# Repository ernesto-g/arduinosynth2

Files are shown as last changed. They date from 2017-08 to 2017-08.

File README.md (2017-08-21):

# Arduino digital polyphonic synth with analog filter

Six voices synth with MIDI input controlled by an arduino microcontroller. 

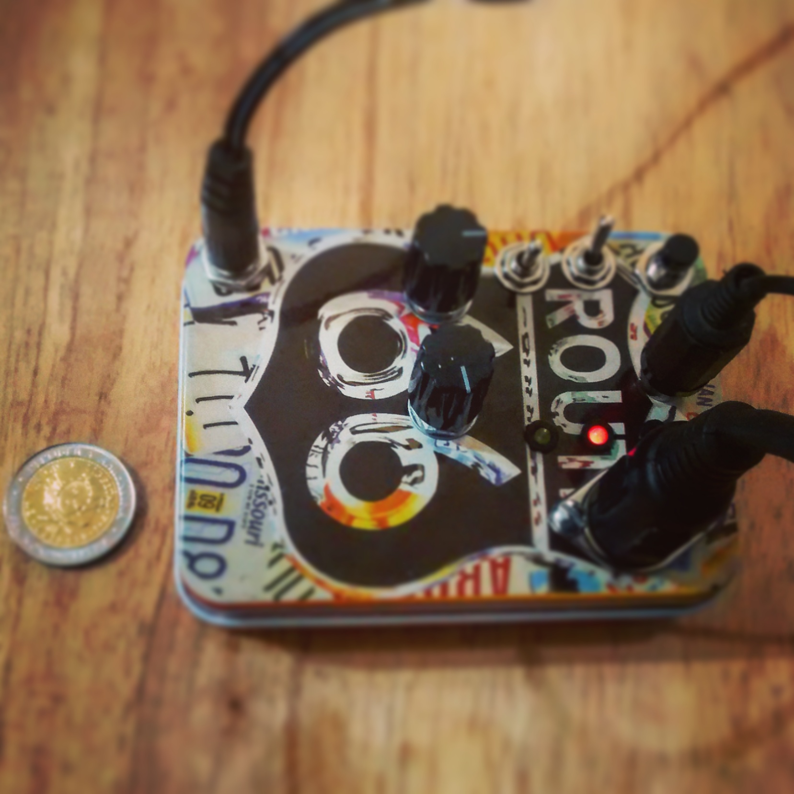
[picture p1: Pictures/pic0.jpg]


Synth features:
  - MIDI input
  - 76 key support (21 to 96)
  - Six digital voices:
    - square waveform 50%
    - square waveform 25%  
  - Two envolope generators (EG) with attack, and release controls
  - One digital 8 bit LFO with:
    - 0.5Hz to 30Hz tune control.
    - Sine and exponential waveforms
  - One analog filter with:
	- Cutoff freq and resonance controls.
	- Modulated by LFO and EG2
  - One digital VCA modulated by EG1 and LFO
  - Digital features:
      - Arpeggiator: Repeat until 10 keys pressed at the same time with speed control.
      - Two modes: 
        - MODE 0:EG with attack and release parameters.
        - MODE 1:EG with attack, sustain and release parameters.

  - MIDI controls info:
      - MIDI channel : 1  
      - EG1 Attack   : control number 74
      - EG1 Release  : control number 71
      - EG2 Attack   : control number 73
      - EG2 Release  : control number 72
      - LFO Speed    : control number 75
      - VCA modulation (EG1 or LFO balance) : control number 77
      - VCF modulation (EG2 or LFO balance) : control number 76
      - Arpeggiator speed : control number 78

This project contains:
  - Arduino nano Firmware
  - Schematics and PCB

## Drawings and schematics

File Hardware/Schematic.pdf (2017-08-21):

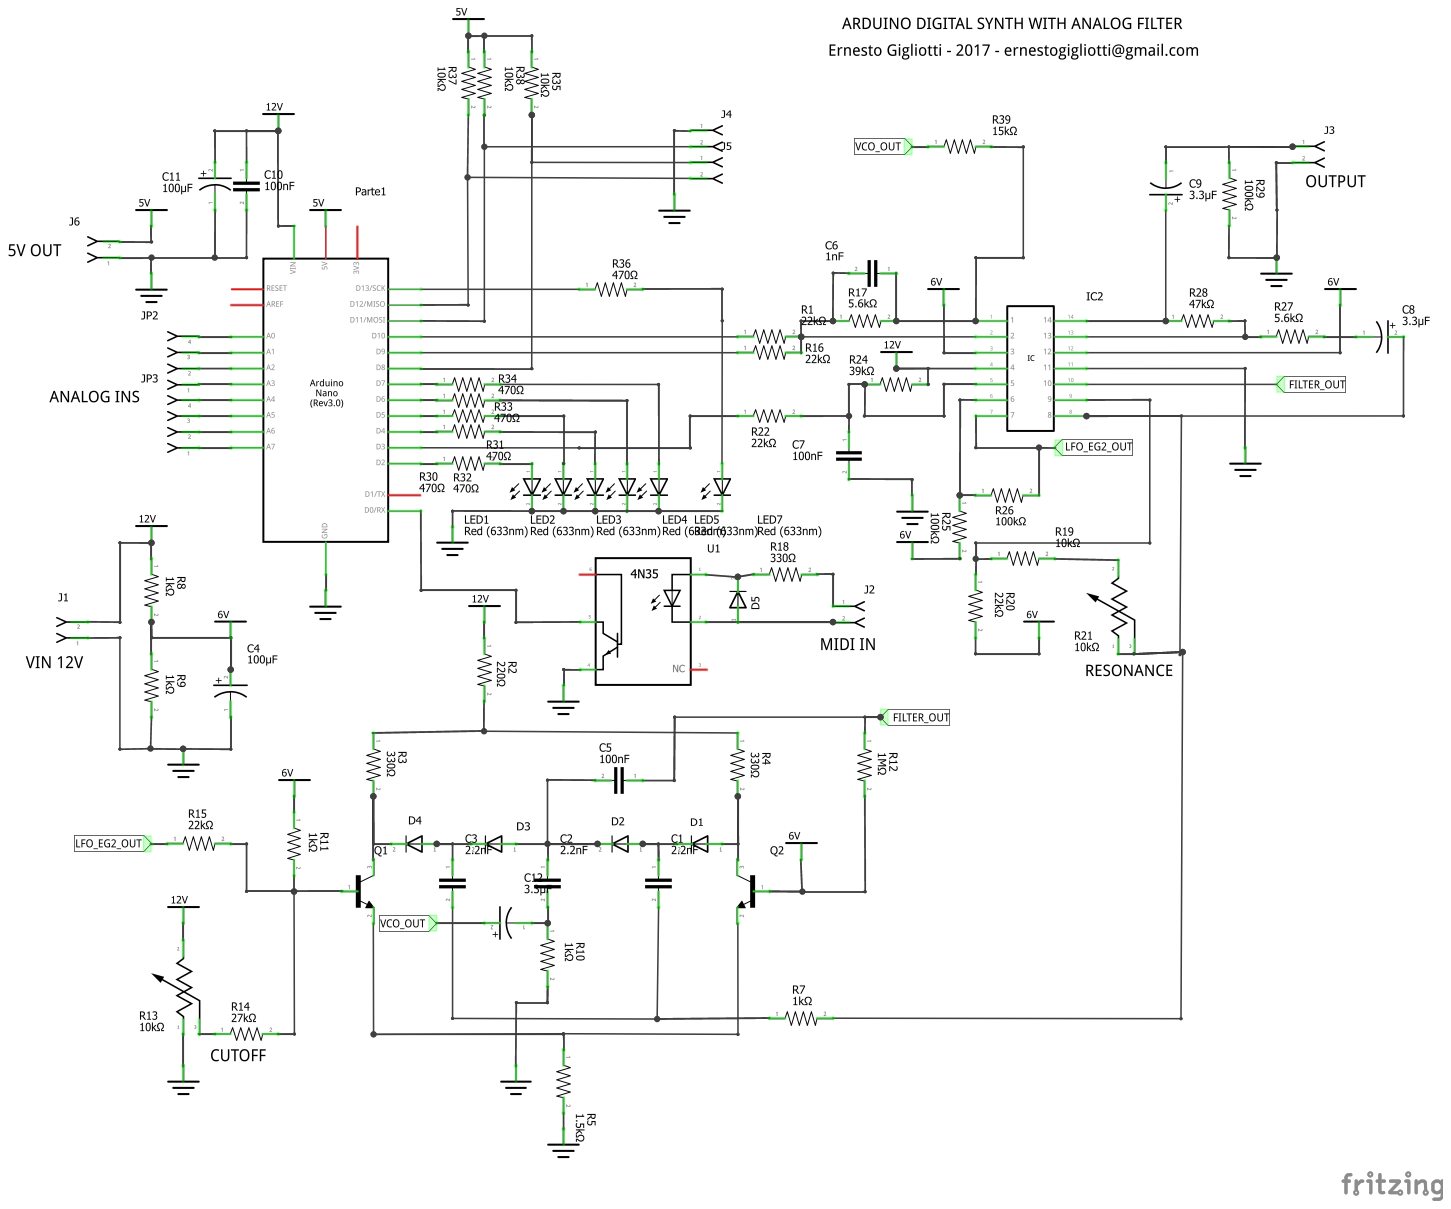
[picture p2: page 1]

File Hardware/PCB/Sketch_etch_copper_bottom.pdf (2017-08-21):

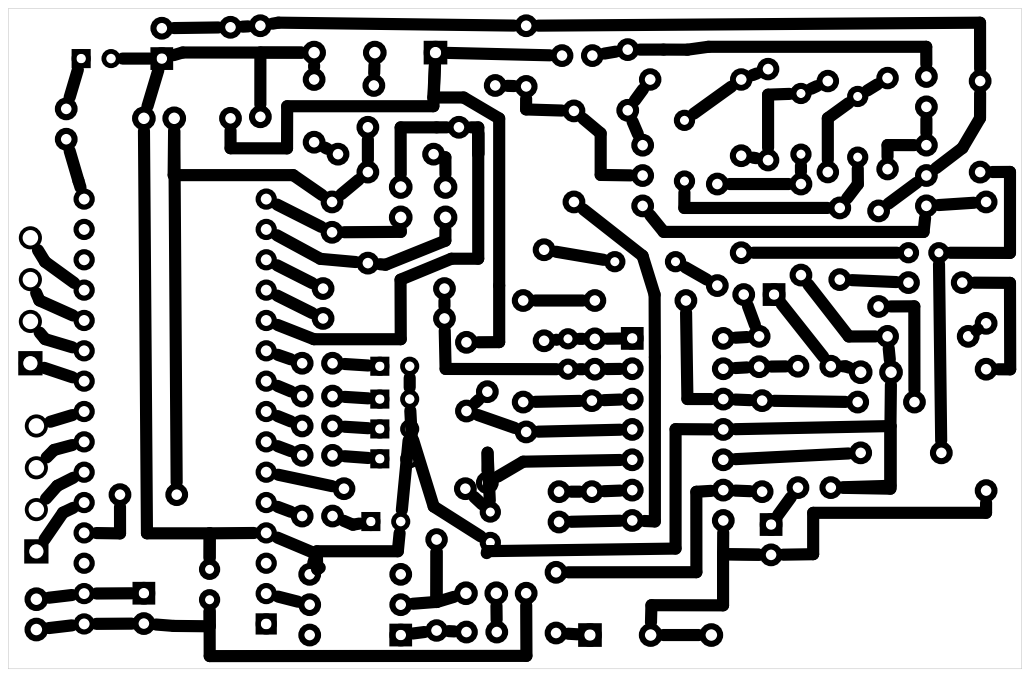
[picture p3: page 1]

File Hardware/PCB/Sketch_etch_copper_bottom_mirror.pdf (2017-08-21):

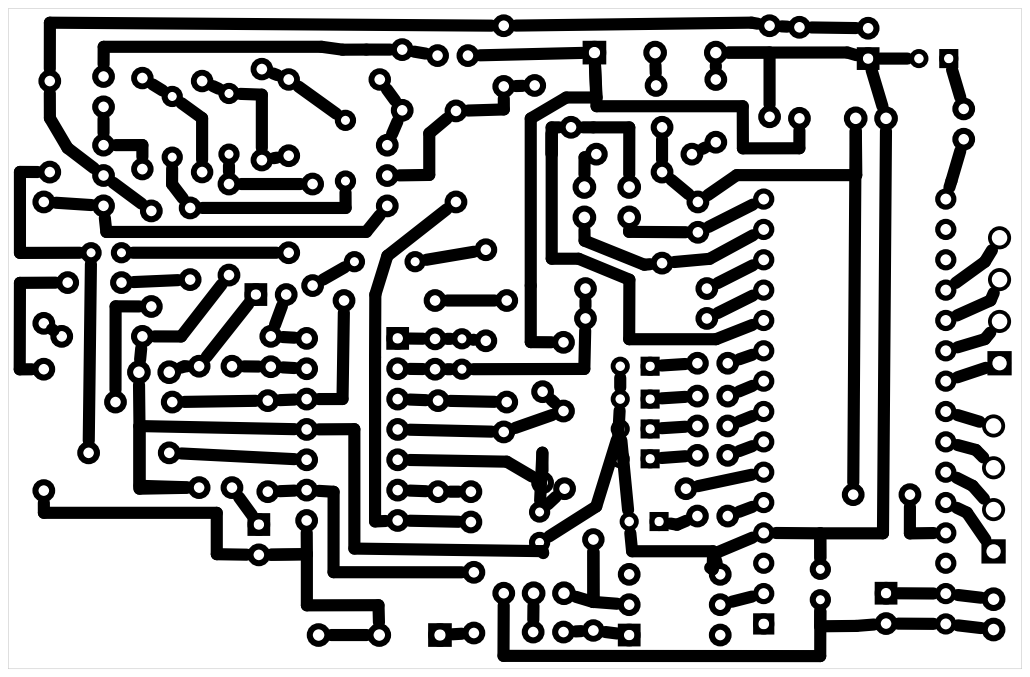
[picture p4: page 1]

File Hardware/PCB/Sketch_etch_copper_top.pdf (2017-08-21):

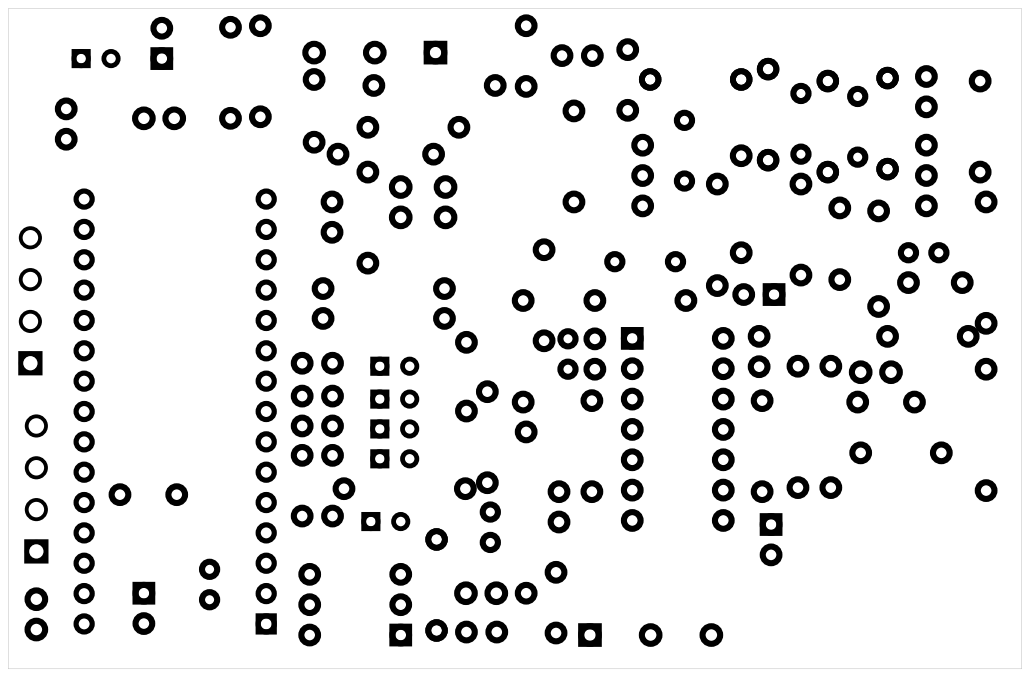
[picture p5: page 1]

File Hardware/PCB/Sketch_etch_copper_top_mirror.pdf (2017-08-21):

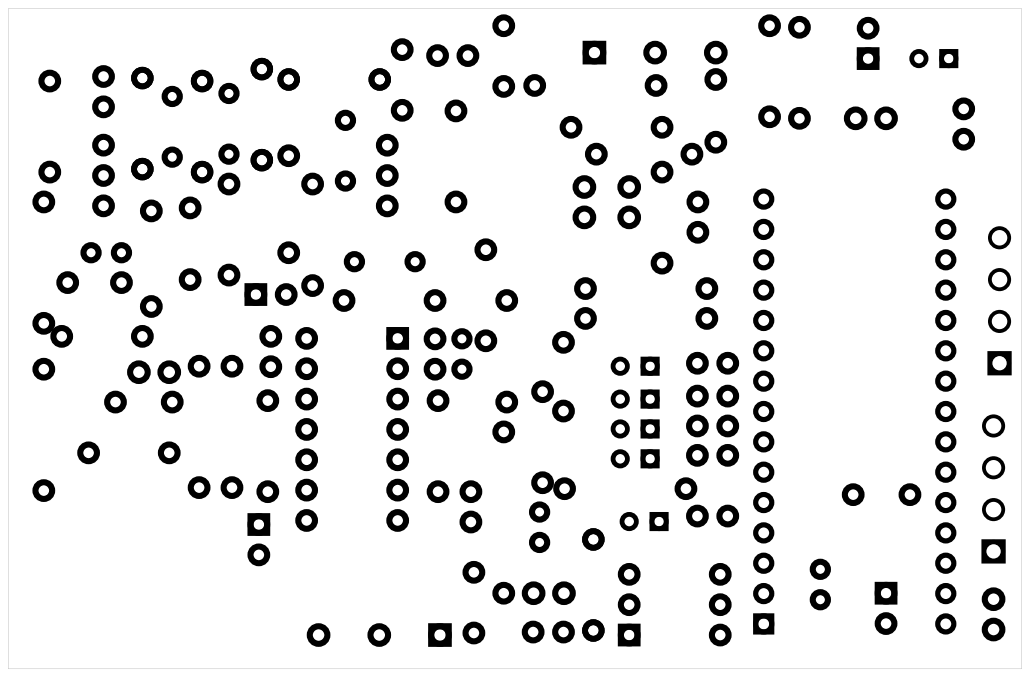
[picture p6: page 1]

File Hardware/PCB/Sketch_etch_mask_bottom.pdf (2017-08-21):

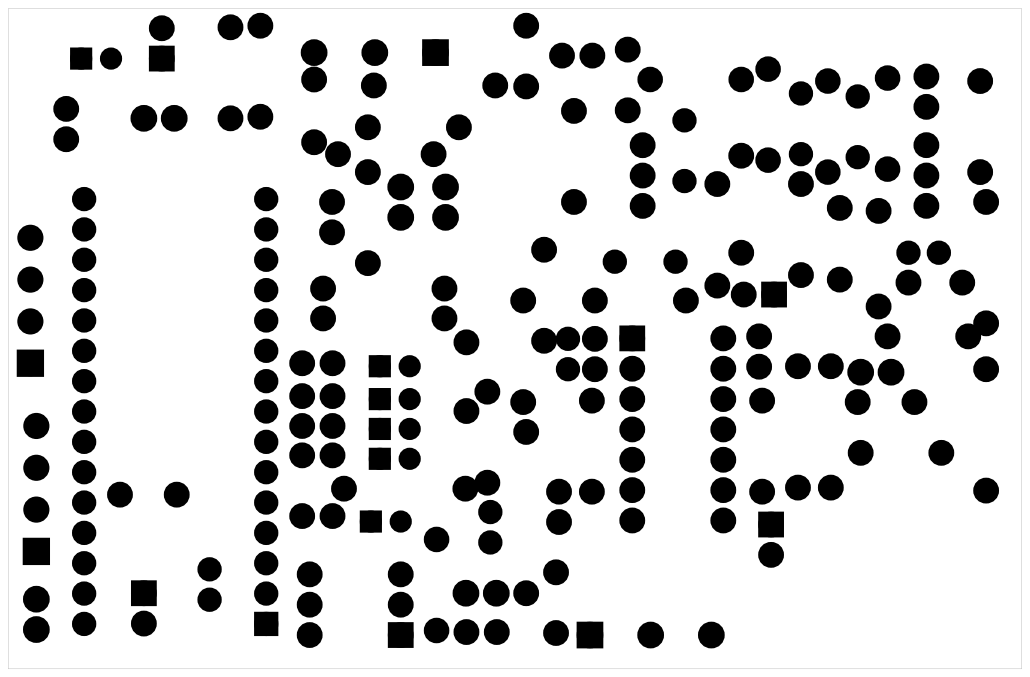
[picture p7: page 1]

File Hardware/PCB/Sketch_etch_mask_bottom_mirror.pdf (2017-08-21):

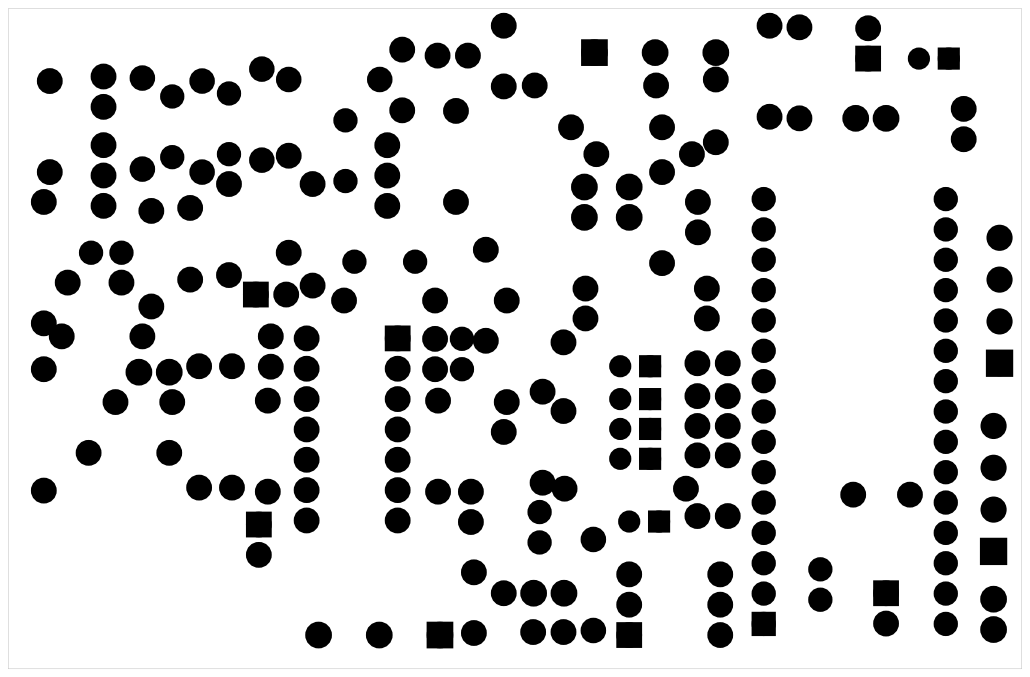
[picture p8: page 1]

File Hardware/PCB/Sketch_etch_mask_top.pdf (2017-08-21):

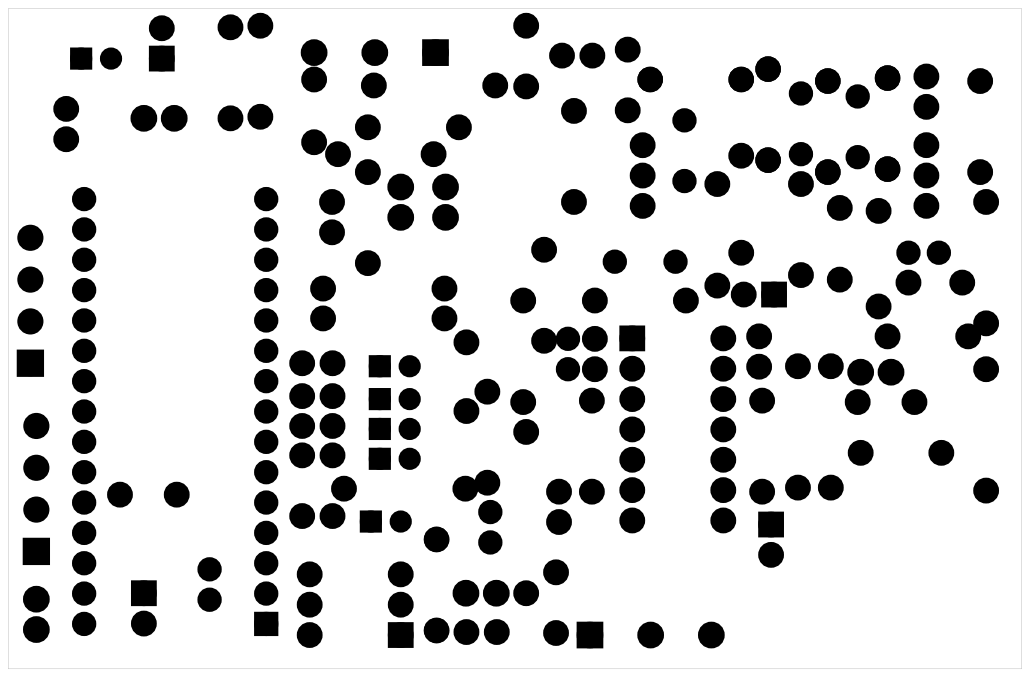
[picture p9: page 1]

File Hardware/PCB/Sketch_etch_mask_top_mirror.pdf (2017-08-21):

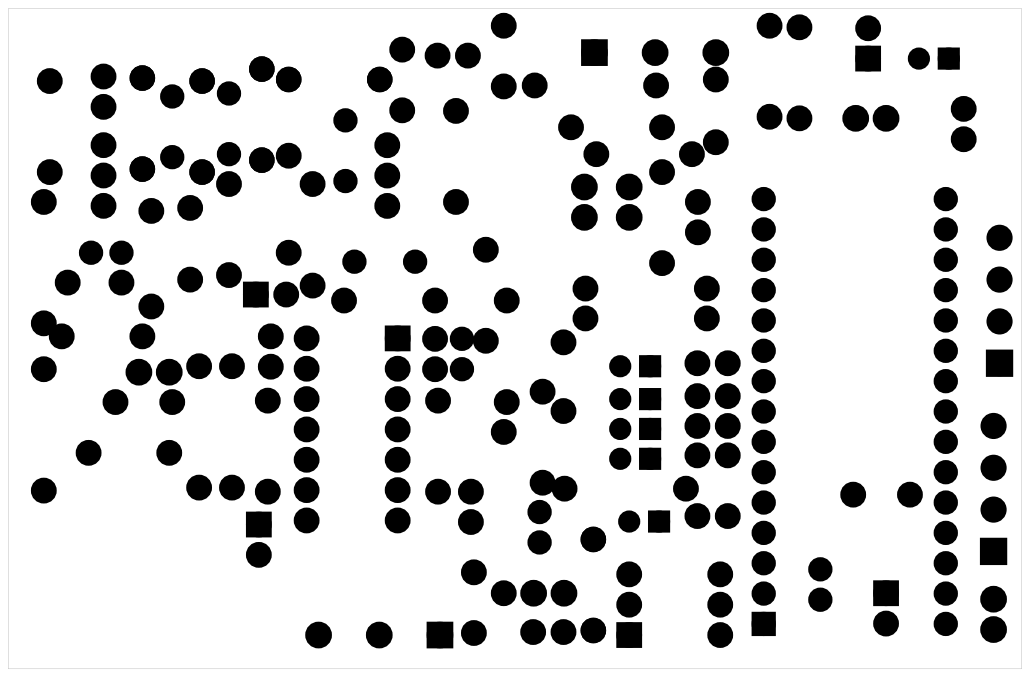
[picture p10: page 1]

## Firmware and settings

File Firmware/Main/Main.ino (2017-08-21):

/**
 *  Arduino Digital Synth with analog filter
    Copyright (C) <2017>  Ernesto Gigliotti <ernestogigliotti@gmail.com>

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
    You should have received a copy of the GNU General Public License
    along with this program.  If not, see <http://www.gnu.org/licenses/>.
 */
#include "Config.h"
#include "MidiManager.h"
#include "Lfo.h"
#include "AnalogIns.h"
#include "FrontPanel.h"
#include "SequencerManager.h"
#include "VCOs.h"

volatile unsigned char bufferRx[5][3];
volatile unsigned char bufferRxIndex[5]={0,0,0,0,0};
volatile unsigned char bufferRxNewPacket[5]={0,0,0,0,0};
volatile unsigned char currentBufferIndex=0;

ISR(USART_RX_vect)
{
    if(bufferRxNewPacket[currentBufferIndex]==0)
    {
      bufferRx[currentBufferIndex][bufferRxIndex[currentBufferIndex]] = UDR0;
      bufferRxIndex[currentBufferIndex]++;
      if(bufferRxIndex[currentBufferIndex]>=3)
      {
        bufferRxNewPacket[currentBufferIndex] = 1;
        currentBufferIndex++;
        if(currentBufferIndex>=5)
          currentBufferIndex=0;
      }
    }
    else
    {
      uint8_t r = UDR0;
      r = r; // silence compiler warnings  
    }
}

void setup() {
  config_init();    
  vcos_init();
  lfo_init();
  ain_init();
  frontp_init();
  seq_init();
  midi_init();
}



void loop() {

  while(1)
  {
    // MIDI Reception
    unsigned char index;
    for(index=0; index<5; index++)
    {
      if(bufferRxNewPacket[index])
      {       
          midi_stateMachine(bufferRx[index][0]);
          midi_stateMachine(bufferRx[index][1]);
          midi_stateMachine(bufferRx[index][2]);      
          bufferRxIndex[index]=0;
          bufferRxNewPacket[index]=0;
      }
    }
    //_______________    

    lfo_cooperativeTimer0Interrupt();


    vcos_egStateMachine();

    midi_repeatManager();

    frontp_state_machine();

    /* //NOT USED
    ain_state_machine();

    seq_stateMachine();
    */
    
  }

}

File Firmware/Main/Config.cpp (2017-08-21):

/**
 *  Arduino Digital Synth with analog filter
    Copyright (C) <2017>  Ernesto Gigliotti <ernestogigliotti@gmail.com>

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
    You should have received a copy of the GNU General Public License
    along with this program.  If not, see <http://www.gnu.org/licenses/>.
 */
//#include <HardwareSerial.h>
#include <Arduino.h>
#include "Config.h"

#define USART_BAUDRATE 31250
#define BAUD_PRESCALE (((F_CPU / (USART_BAUDRATE * 16UL))) - 1)
 
void config_init(void)
{
  
  // Configure serial port for MIDI input
  //Serial.begin(31250); 
    UBRR0L = (uint8_t)(BAUD_PRESCALE & 0xff);
    UBRR0H = (uint8_t)(BAUD_PRESCALE >> 8);
    UCSR0B =
        /* interrupt on receive */
        (1 << RXCIE0) | (1 << TXEN0) |
        (1 << RXEN0);
    UCSR0C =
        /* no parity bit */
        (0 << UPM01) |
        (0 << UPM00) |
        /* asyncrounous USART */
        (0 << UMSEL01) |
        (0 << UMSEL00) |
        /* one stop bit */
        (0 << USBS0) |
        /* 8-bits of data */
        (1 << UCSZ01) |
        (1 << UCSZ00);

    DDRD = 0x00;
    DDRB = 0x20;  
  //_____________________________________


  // Configure TIMER1 for PWM (VCO1 and VCO2 Control Voltage)
  DDRB |= (1 << DDB1) | (1 << DDB2);
  TCCR1A =
      (1 << COM1A1) | (1 << COM1B1) |
      // Fast PWM mode.
      (1 << WGM11);
  TCCR1B =
      // Fast PWM mode.
      (1 << WGM12) | (1 << WGM13) |
      // No clock prescaling (fastest possible
      // freq).
      (1 << CS10);
  OCR1A = 0;
  OCR1B = 0;
  //ICR1 = 512;//31khz
  //ICR1 = 384; // 41Khz
  //ICR1 = 192;
  //ICR1 = 164; // 96Khz
  ICR1 = 96; // OK
  //ICR1 = 144; // OK
  //__________________________


  // Configure TIMER2 for PWM (LFO output)
  DDRD |= (1 << DDD3);
  TCCR2A =
      (1 << COM2B1) |
      // Fast PWM mode.
      (1 << WGM20) | (1 << WGM21);
  TCCR2B =
      // No clock prescaling (fastest possible
      // freq).
      (1 << CS20);
  OCR2A = 0;
  OCR2B = 0;
  //ICR2 = 255;
  //__________________________
  
  // Configure TIMER0 for DDS interrupt
  cli();//stop interrupts
  // each 133uS 
  TCCR0A = 0;// set entire TCCR0A register to 0
  TCCR0B = 0;// same for TCCR0B
  TCNT0  = 0;//initialize counter value to 0
  // set compare match register for 2khz increments

  OCR0A = 12; // 52uS 
  //OCR0A = 9; // 42uS // falla recepcion uart

  // turn on CTC mode
  TCCR0A |= (1 << WGM01);
  // Set CS01 and CS00 bits for 64 prescaler
  TCCR0B |= (1 << CS01) | (1 << CS00);   
  // enable timer compare interrupt
  TIMSK0 |= (1 << OCIE0A);
  sei();//allow interrupts
  //___________________________________
  

  // Init Pins
  pinMode(PIN_LED_MODE0,OUTPUT);
  digitalWrite(PIN_LED_MODE0,LOW);

  pinMode(PIN_LED_MODE1,OUTPUT);
  digitalWrite(PIN_LED_MODE1,LOW);

  pinMode(PIN_LED_REPEAT,OUTPUT);
  digitalWrite(PIN_LED_REPEAT,LOW);

  pinMode(PIN_BUTTON,INPUT);
  pinMode(PIN_VCO_WAVEFORM_SWITCH,INPUT);
  pinMode(PIN_LFO_WAVEFORM_SWITCH,INPUT);

  //__________
   
 }


void USART_Transmit( unsigned char data )
{
 /* Wait for empty transmit buffer */
 while ( !( UCSR0A & (1<<5)) );
 /* Put data into buffer, sends the data */
 UDR0 = data;
}
void printHex(byte val)
{
  byte h = val>>4;
  if(h<=9)
    h = h + '0';
  else
    h = (h-0x0A) + 'A';
    
  byte l = val&0x0F;
  if(l<=9)
    l = l + '0';
  else
    l = (l-0x0A) + 'A';

  USART_Transmit('0');
  USART_Transmit('x');
  USART_Transmit(h);
  USART_Transmit(l);
  USART_Transmit(' ');
}

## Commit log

2017-08-21 gliss deleted. switch for vco waveform
2017-08-21 midi controls scales fixed
    [Main.ino, MidiManager.cpp]
2017-08-21 76 key support. readme file. hardware data
    [Fritzing_project.fzz]

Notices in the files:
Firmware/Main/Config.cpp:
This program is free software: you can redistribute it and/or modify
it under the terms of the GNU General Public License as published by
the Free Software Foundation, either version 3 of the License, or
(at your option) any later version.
